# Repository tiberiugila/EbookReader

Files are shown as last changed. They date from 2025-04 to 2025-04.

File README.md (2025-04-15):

# OpenBook E-Reader

## Overview
OpenBook is a cutting-edge electronic reading device built around the ESP32-C6 microcontroller. This sophisticated gadget integrates multiple sensors and interfaces to deliver an energy-efficient reading experience with extended functionality.

## Project Gallery
The project includes various design views that showcase:
- Device exploded assembly view
- PCB layout visualization
- Component arrangement
- 3D model renderings
- Enclosure design details

## Components List (BOM)

| Componenta | Link achizitie | Link datasheet |
|---|---|---|
| 112A-TAAR-R03 ATTEND | https://store.comet.srl.ro/Catalogue/Product/43497/ | https://www.snapeda.com/parts/112A-TAAR-R03/Attend/datasheet/ |
| BD5229G-TR | https://www.digikey.com/en/products/detail/rohm-semiconductor/BD5229G-TR/3663792 | https://fscdn.rohm.com/en/products/databook/datasheet/ic/power/voltage_detector/bd52xxg-e.pdf |
| ESP32 WROVER BME680 Sensor | https://store.comet.srl.ro/Catalogue/Product/50164/ | https://www.bosch-sensortec.com/media/boschsensortec/downloads/datasheets/bst-bme680-ds001.pdf |
| LED CHG_LED | https://ro.mouser.com/ProductDetail/Kingbright/KP-1608SURCK?qs=2JU0tDl2GZ3FuyEWfBV1%2Fg== | https://www.snapeda.com/parts/KP-1608SURCK/Kingbright/datasheet/ |
| Condensator C0402 | https://ro.mouser.com/c/passive-components/capacitors/ceramic-capacitors/?q=CC0402 | https://componentsearchengine.com/Datasheets/2/CC0402MRX5R5BB106.pdf |
| Condensator Tant | https://ro.mouser.com/ProductDetail/KYOCERA-AVX/TAJW107M010RNJ?qs=Wtp%252Bf%2FAeVqIH8v1VxV%252B1Rg%3D%3D | https://ro.mouser.com/datasheet/2/40/TAJ-3165264.pdf |
| Q1 DMG2305UX-7 | https://www.digikey.com/en/products/detail/diodes-incorporated/DMG2305UX-7/4340666 | https://www.diodes.com/assets/Datasheets/DMG2305UX.pdf |
| RTC MODULE DS3231SN# | https://www.snapeda.com/parts/DS3231SN%23/Analog+Devices/view-part/?ref=eda | https://www.snapeda.com/parts/DS3231SN%23/Analog%20Devices/datasheet/ |
| ESP32 C6 WROOM-1-N8 | https://ro.mouser.com/ProductDetail/Espressif-Systems/ESP32-C6-WROOM-1-N8?qs=8Wlm6%252BaMh8ST02Gmwp74cw%3D%3D | https://www.snapeda.com/parts/ESP32-C6-WROOM-1-N8/Espressif%20Systems/datasheet/ |
| FH34SRJ-24S-0.5SH(99) | https://ro.mouser.com/ProductDetail/Hirose-Connector/FH34SRJ-24S-0.5SH99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 | https://www.snapeda.com/parts/FH34SRJ-24S-0.5SH(99)/Hirose%20Connector/datasheet/ |
| MAX 17048G+T10 | https://www.snapeda.com/parts/MAX17048G+T10/Analog+Devices/view-part/?ref=eda | https://www.snapeda.com/parts/MAX17048G+T10/Analog%20Devices/datasheet/ |
| MBR0530 Schottky Diode | https://www.snapeda.com/parts/MBR0530/Onsemi/view-part/?ref=snap | https://www.snapeda.com/parts/MBR0530/ON%20Semiconductor/datasheet/ |
| MCP73831 Power Management | https://www.snapeda.com/parts/MCP73831T-2ACI/OT/Microchip/datasheet/ | https://www.snapeda.com/parts/MCP73831T-2ACI/OT/Microchip/datasheet/ |
| PFMF.050.1 | https://ro.mouser.com/ProductDetail/EPCOS-TDK/B72520T0350K062?qs=dEfas%2FXlABIszF52uu7vrg%3D%3D | https://www.tdk-electronics.tdk.com/inf/75/db/CTVS_14/Surge_protection_series.pdf |
| PGB1010603MR | https://www.snapeda.com/parts/PGB1010603MR/Littelfuse/view-part/?ref=eda | https://www.snapeda.com/parts/PGB1010603MR/Littelfuse%20Inc./datasheet/ |
| QWIIC_RIGHT_ANGLE CONNECTOR | https://ro.mouser.com/ProductDetail/SparkFun/PRT-14417?qs=wd5RIQLrsJhgdz%2FpmZ%2F3GQ== | https://ro.mouser.com/datasheet/2/813/Qwiic_Connector_Datasheet-1223982.pdf |
| Rezistenta R0402 | https://grabcad.com/library/resistor-0402-1) | https://www.yageo.com/upload/media/product/products/datasheet/rchip/PYu-RC_Group_51_RoHS_L_12.pdf |
| SD0805S020S1R0 | https://ro.mouser.com/ProductDetail/KYOCERA-AVX/SD0805S020S1R0?qs=jCA%252BPfw4LHbpkAoSnwrdjw%3D%3D | https://ro.mouser.com/datasheet/2/40/schottky-3165252.pdf |
| Si1308EDL-T1-GE3 MOSFET | https://www.snapeda.com/parts/SI1308EDL-T1-GE3/Vishay+Siliconix/view-part/?welcome=home&ref=eda | https://www.snapeda.com/parts/SI1308EDL-T1-GE3/Vishay%20Siliconix/datasheet/ |
| USB4110-GF-A | https://ro.mouser.com/ProductDetail/GCT/USB4110-GF-A?qs=KUoIvG%2F9IlYiZvIXQjyJeA%3D%3D | https://ro.mouser.com/datasheet/2/837/GCT_USB4110_Product_Drawing___20k_cycles-3455479.pdf |
| USBLC6-2SC6Y | https://ro.mouser.com/ProductDetail/STMicroelectronics/USBLC6-2SC6Y?qs=gNDSiZmRJS%2FOgDexvXkdow%3D%3D | https://ro.mouser.com/datasheet/2/389/usblc6_2sc6y-1852505.pdf |
| W25Q512JVEIQ | https://www.snapeda.com/parts/W25Q512JVEIQ/Winbond+Electronics/view-part/?ref=eda | https://www.winbond.com/resource-files/W25Q512JV%20SPI%20RevB%2006252019%20KMS.pdf |
| XC6220A331MR-G | https://componentsearchengine.com/part-view/XC6220A331MR-G/Torex | https://product.torexsemi.com/system/files/series/xc6220.pdf |
| 744043680 BOBINA | https://ro.mouser.com/ProductDetail/Wurth-Elektronik/744043680?qs=PGXP4M47uW6VkZq%252BkzjrHA%3D%3D | https://www.we-online.com/components/products/datasheet/744043680.pdf |

## Hardware Capabilities

### Processing & Connectivity
The ESP32-C6 serves as the heart of OpenBook, providing Wi-Fi 6 and Bluetooth 5.0 LE connectivity. Its extensive GPIO capabilities enable seamless integration with various peripheral components.

### Display Technology
The e-paper display connects through an SPI interface and utilizes the BD5229G-TR driver for voltage management. MOSFET-controlled power distribution enables complete shutdown when not in use, significantly enhancing energy efficiency.

### Environmental Monitoring
The BME688 sensor delivers comprehensive environmental data including temperature, humidity, barometric pressure, and air quality (VOC) readings via I2C interface.

### Power Systems
The device features:
- MCP73831-based charging circuit supporting up to 500mA charging current
- MAX17048G+T10 battery monitoring system providing detailed charge level information
- Energy-efficient design for extended reading time

## ESP32-C6 Pin Allocation

| Component | Connected Pins | Protocol | Function |
|---|---|---|---|
| E-Paper Display | IO12, IO11, IO5, IO4| SPI | Display control and reset |
| BME688 Sensor | IO8, IO10 | I2C | Environmental monitoring |
| SD Card Interface | IO7 | SPI | External storage |
| RTC Module | IO8, IO10 | I2C | Real-time clock (shared I2C bus) |
| USB Interface | IO16, IO17 | UART | Programming and debugging |

## Implementation Process

1. Electronic schematic design and ESP32-C6 component integration
2. 2D layout development and component placement
3. Signal and power trace routing
4. Ground plane implementation on both PCB layers
5. Trace width and clearance rule application
6. Strategic connector positioning (Qwiic, USB-C)
7. Test pad placement for debugging
8. 3D model generation and mechanical compatibility verification

## Technical Notes

- Test points have been strategically positioned near board edges and critical components for easy access during testing and debugging
- Surface-mount diode pad sizes were adjusted from initial specifications to ensure reliable electrical connections and easier assembly
- Trace routing utilizes both top and bottom PCB layers for efficient signal and power distribution
- Ground planes have been implemented on both layers to optimize electrical performance

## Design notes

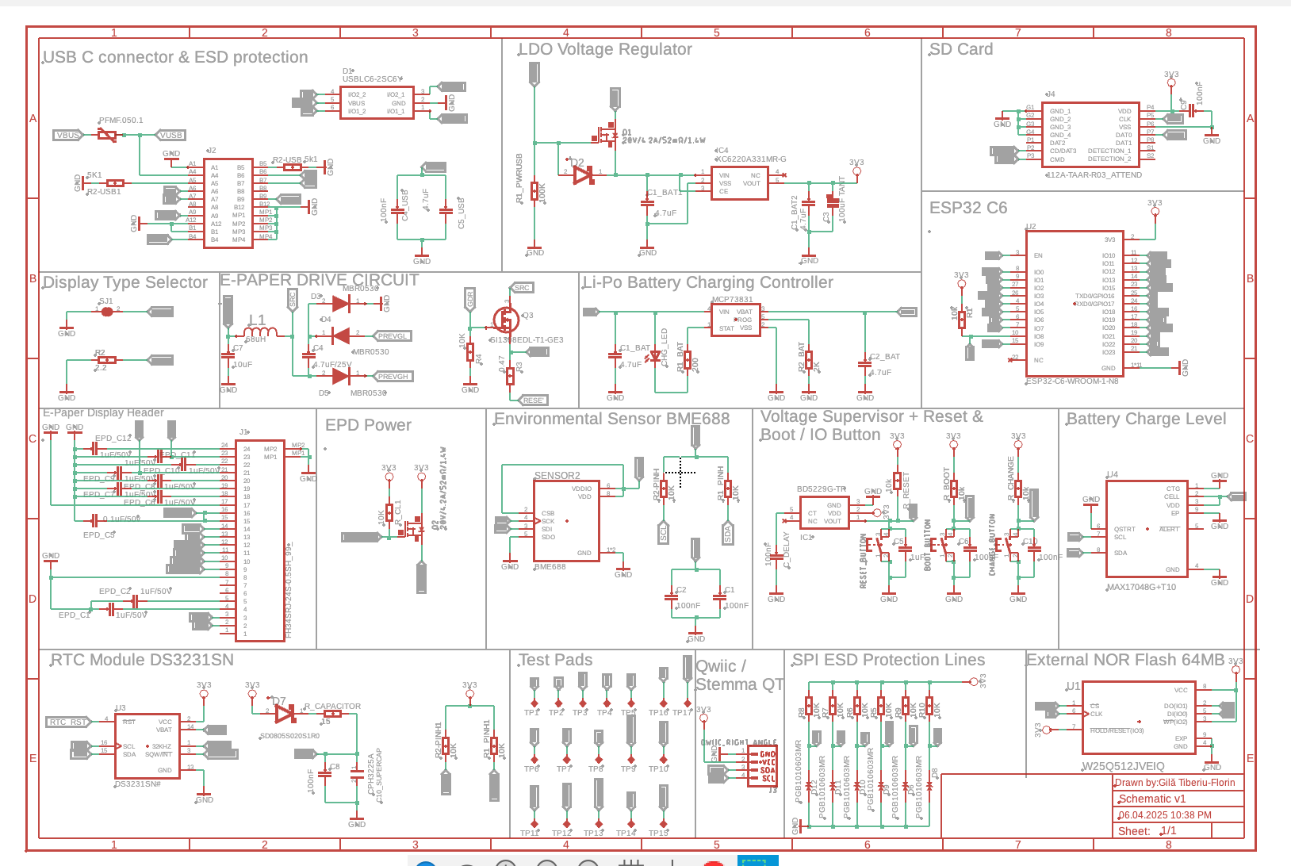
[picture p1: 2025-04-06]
Images/Schematic.png

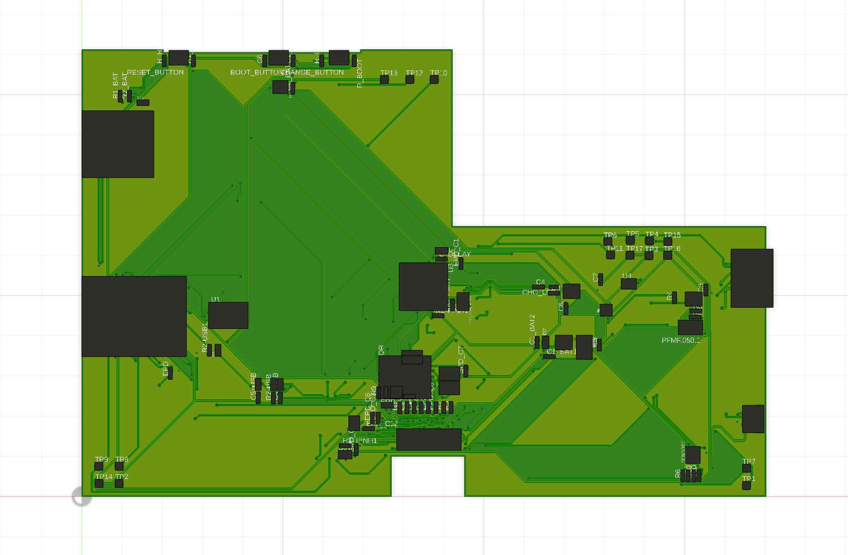
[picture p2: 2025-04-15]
Images/3D Model.png

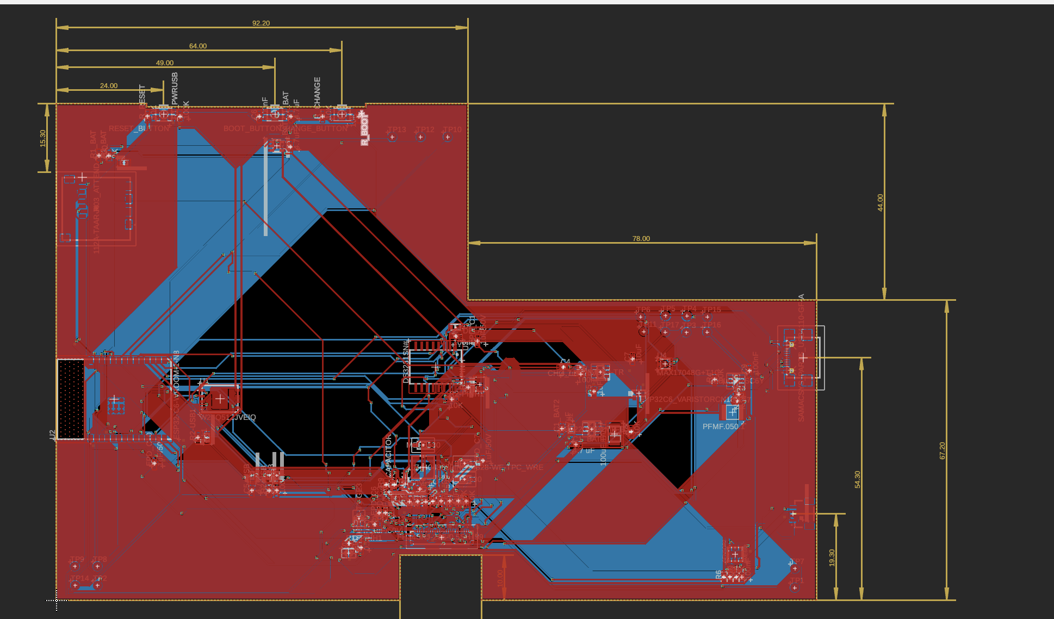
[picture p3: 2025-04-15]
Images/PCB.png

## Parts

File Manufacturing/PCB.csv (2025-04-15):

Qty | Value | Device | Package | Parts | Description | ARROW_PART_NUMBER | ARROW_PRICE-STOCK | AVAILABILITY | CENTROID_NOT_SPECIFIED | CHECK_PRICES | COPYRIGHT | DATASHEET | DESCRIPTION | DIGIKEY_DESCRIPTION | DIGIKEY_PART_NUMBER | DMG2305UX-7 | HEIGHT | LEAD_FREE | MANUFACTURER_NAME | MANUFACTURER_PART_NUMBER | MF | MFR_NAME | MOUSER_PART_NUMBER | MOUSER_PRICE-STOCK | MOUSER_TESTING_PART_NUMBER | MOUSER_TESTING_PRICE-STOCK | MP | MPN | PACKAGE | POPULARITY | PREFIX | PRICE | PROD_ID | PURCHASE-URL | ROHS | SNAPEDA_LINK | SPICEMODEL | SPICEPREFIX | TEMPERATURE_RANGE_HIGH | TEMPERATURE_RANGE_LOW | THERMALLOSS | TP_SIGNAL_NAME | VALUE
1 |  | ADAFRUIT_LEDCHIP-LED0603 | ADAFRUIT_CHIP-LED0603 | CHG_LED | LED
1 |  | SJ | SJ | SJ1 | SMD solder JUMPER |  |  |  |  |  |  |  |  |  |  |  |  |  |  |  |  |  |  |  |  |  |  |  |  | 3
1 | 0.1uF/50V | ESP32_WROVER_EAGLE-LTSPICE_CC0402 | ESP32_WROVER_EAGLE-LTSPICE_C0402 | EPD_C5 | CAPACITOR, European symbol |  |  |  |  |  |  |  |  |  |  |  |  |  |  |  |  |  |  |  |  |  |  |  |  |  |  |  |  |  |  |  | NONE | C
1 | 0.47 | ESP32_WROVER_EAGLE-LTSPICE_RR0402 | ESP32_WROVER_EAGLE-LTSPICE_R0402 | R3 | RESISTOR, European symbol |  |  |  |  |  |  |  |  |  |  |  |  |  |  |  |  |  |  |  |  |  |  |  |  |  |  |  |  |  |  |  | NONE | R
1 | 100K | ESP32_WROVER_EAGLE-LTSPICE_RR0402 | ESP32_WROVER_EAGLE-LTSPICE_R0402 | R1_PWRUSB | RESISTOR, European symbol |  |  |  |  |  |  |  |  |  |  |  |  |  |  |  |  |  |  |  |  |  |  |  |  |  |  |  |  |  |  |  | 100K | R
1 | 100nF | EAGLE-LTSPICE_CC0402 | EAGLE-LTSPICE_C0402 | C9 | CAPACITOR, European symbol |  |  |  |  |  |  |  |  |  |  |  |  |  |  |  |  |  |  |  |  |  |  |  |  |  |  |  |  |  |  |  | NONE | 100nF
1 | 100nF | EAGLE-LTSPICE_CC0402 | EAGLE-LTSPICE_C0402 | C4_USB | CAPACITOR, European symbol |  |  |  |  |  |  |  |  |  |  |  |  |  |  |  |  |  |  |  |  |  |  |  |  |  |  |  |  |  |  |  | NONE | C
6 | 100nF | ESP32_WROVER_EAGLE-LTSPICE_CC0402 | ESP32_WROVER_EAGLE-LTSPICE_C0402 | C1, C2, C6, C8, C10, C_DELAY | CAPACITOR, European symbol |  |  |  |  |  |  |  |  |  |  |  |  |  |  |  |  |  |  |  |  |  |  |  |  |  |  |  |  |  |  |  | NONE | C
1 | 100uF TANT | RCL_CPOL-EUCT3528 | RCL_CT3528 | C3 | POLARIZED CAPACITOR, European symbol |  |  |  |  |  |  |  |  |  |  |  |  |  |  |  |  |  |  |  |  |  |  |  |  | 0 |  |  |  |  |  |  |  | 100uF TANT
16 | 10K | ESP32_WROVER_EAGLE-LTSPICE_RR0402 | ESP32_WROVER_EAGLE-LTSPICE_R0402 | R1, R1_PINH, R1_PINH1, R2-PINH, R2-PINH1, R4, R5, R6, R7, R8, R9, R10, R_BOOT, R_CHANGE, R_CL1, R_RESET | RESISTOR, European symbol |  |  |  |  |  |  |  |  |  |  |  |  |  |  |  |  |  |  |  |  |  |  |  |  |  |  |  |  |  |  |  | NONE | R
1 | 10uF | ESP32_WROVER_EAGLE-LTSPICE_CC0402 | ESP32_WROVER_EAGLE-LTSPICE_C0402 | C7 | CAPACITOR, European symbol |  |  |  |  |  |  |  |  |  |  |  |  |  |  |  |  |  |  |  |  |  |  |  |  |  |  |  |  |  |  |  | NONE | C
1 | 112A-TAAR-R03_ATTEND | 112A-TAAR-R03_ATTEND | 112ATAARR03ATTEND | J4 | Micro SD Card Socket, Push-Push Type, Top Mount, SMT, H=1.83mm, 10u |  |  |  |  |  |  |  | Micro SD Card Socket | Push-Push Type | Top Mount | SMT | H=1.83mm | 10u |  |  |  | 1.9mm |  | ATTEND | 112A-TAAR-R03 ATTEND
1 | 15 | ESP32_WROVER_EAGLE-LTSPICE_RR0402 | ESP32_WROVER_EAGLE-LTSPICE_R0402 | R_CAPACITOR | RESISTOR, European symbol |  |  |  |  |  |  |  |  |  |  |  |  |  |  |  |  |  |  |  |  |  |  |  |  |  |  |  |  |  |  |  | NONE | R
1 | 1uF | ESP32_WROVER_EAGLE-LTSPICE_CC0402 | ESP32_WROVER_EAGLE-LTSPICE_C0402 | C5 | CAPACITOR, European symbol |  |  |  |  |  |  |  |  |  |  |  |  |  |  |  |  |  |  |  |  |  |  |  |  |  |  |  |  |  |  |  | NONE | C
6 | 1uF/50V | ESP32_WROVER_EAGLE-LTSPICE_CC0402 | ESP32_WROVER_EAGLE-LTSPICE_C0402 | EPD_C6, EPD_C7, EPD_C8, EPD_C9, EPD_C10, EPD_C11 | CAPACITOR, European symbol |  |  |  |  |  |  |  |  |  |  |  |  |  |  |  |  |  |  |  |  |  |  |  |  |  |  |  |  |  |  |  | NONE | C
3 | 1uF/50V | ESP32_WROVER_EAGLE-LTSPICE_CC0402 | ESP32_WROVER_EAGLE-LTSPICE_C0402 | EPD_C1, EPD_C2, EPD_C12 | CAPACITOR, European symbol |  |  |  |  |  |  |  |  |  |  |  |  |  |  |  |  |  |  |  |  |  |  |  |  |  |  |  |  |  |  |  | NONE | C
1 | 2.2 | ESP32_WROVER_EAGLE-LTSPICE_RR0402 | ESP32_WROVER_EAGLE-LTSPICE_R0402 | R2 | RESISTOR, European symbol |  |  |  |  |  |  |  |  |  |  |  |  |  |  |  |  |  |  |  |  |  |  |  |  |  |  |  |  |  |  |  | 2.2 | R
1 | 200 | ESP32_WROVER_EAGLE-LTSPICE_RR0402 | ESP32_WROVER_EAGLE-LTSPICE_R0402 | R1_BAT | RESISTOR, European symbol |  |  |  |  |  |  |  |  |  |  |  |  |  |  |  |  |  |  |  |  |  |  |  |  |  |  |  |  |  |  |  | NONE | R
2 | 20V/4.2A/52mO/1.4W | ESP32_WROVER_SPARKFUN-DISCRETESEMI_MOSFET_PCH-DMG2305UX-7 | ESP32_WROVER_SPARKFUN-DISCRETESEMI_SOT23-3 | Q1, Q2 | P-channel MOSFETs |  |  |  |  |  |  |  |  |  |  |  |  |  |  |  |  |  |  |  |  |  |  |  |  |  |  |  | TRAN-14388 |  |  |  |  |  |  |  |  |  | 20V/4.2A/52mO/1.4W
1 | 2K | ESP32_WROVER_EAGLE-LTSPICE_RR0402 | ESP32_WROVER_EAGLE-LTSPICE_R0402 | R2_BAT | RESISTOR, European symbol |  |  |  |  |  |  |  |  |  |  |  |  |  |  |  |  |  |  |  |  |  |  |  |  |  |  |  |  |  |  |  | NONE | R
1 | 4.7 uF | EAGLE-LTSPICE_CC0402 | EAGLE-LTSPICE_C0402 | C1_BAT1 | CAPACITOR, European symbol |  |  |  |  |  |  |  |  |  |  |  |  |  |  |  |  |  |  |  |  |  |  |  |  |  |  |  |  |  |  |  | NONE | C |  |  | 4.7 uF
1 | 4.7uF | EAGLE-LTSPICE_CC0402 | EAGLE-LTSPICE_C0402 | C1_BAT2 | CAPACITOR, European symbol |  |  |  |  |  |  |  |  |  |  |  |  |  |  |  |  |  |  |  |  |  |  |  |  |  |  |  |  |  |  |  | NONE | 4.7uF
1 | 4.7uF | EAGLE-LTSPICE_CC0402 | EAGLE-LTSPICE_C0402 | C5_USB | CAPACITOR, European symbol |  |  |  |  |  |  |  |  |  |  |  |  |  |  |  |  |  |  |  |  |  |  |  |  |  |  |  |  |  |  |  | NONE | C
2 | 4.7uF | ESP32_WROVER_EAGLE-LTSPICE_CC0402 | ESP32_WROVER_EAGLE-LTSPICE_C0402 | C1_BAT, C2_BAT | CAPACITOR, European symbol |  |  |  |  |  |  |  |  |  |  |  |  |  |  |  |  |  |  |  |  |  |  |  |  |  |  |  |  |  |  |  | NONE | C
1 | 4.7uF/25V | ESP32_WROVER_EAGLE-LTSPICE_CC0402 | ESP32_WROVER_EAGLE-LTSPICE_C0402 | C4 | CAPACITOR, European symbol |  |  |  |  |  |  |  |  |  |  |  |  |  |  |  |  |  |  |  |  |  |  |  |  |  |  |  |  |  |  |  | NONE | C
2 | 5k1 | ESP32_WROVER_EAGLE-LTSPICE_RR0402 | ESP32_WROVER_EAGLE-LTSPICE_R0402 | R2-USB, R2-USB1 | RESISTOR, European symbol |  |  |  |  |  |  |  |  |  |  |  |  |  |  |  |  |  |  |  |  |  |  |  |  |  |  |  |  |  |  |  | NONE | R
1 | 744043680IND_4828-WE-TPC_WRE | 744043680IND_4828-WE-TPC_WRE | IND_4828-WE-TPC_WRE | L1 |  |  |  |  |  |  | Copyright (C) 2024 Ultra Librarian. All rights reserved. |  |  |  |  |  |  |  |  | 68uH |  | Wurth Electronics
1 | BD5229G-TR | BD5229G-TR | SOT95P280X125-5N | IC1 | Voltage Detector with Adjustable Delay Time: CMOS processes are utilized to develop high precision, low current consumption CMOS reset ICs that allow arbitrary setting of the delay time. The extensive lineup includes both Nch Open Drain and CMOS output types in a wide range of detection voltages (from 2.3V to 6.0V, in 0.1V steps), enabling selection of the ideal solution based on customer requirements. In addition, the entire series is of course both lead-free and RoHS-compliant. |  |  |  |  |  |  |  | Voltage Detector with Adjustable Delay Time: CMOS processes are utilized to develop high precision | low current consumption CMOS reset ICs that allow arbitrary setting of the delay time. The extensive lineup includes both Nch Open Drain and CMOS output types in a wide range of detection voltages (from 2.3V to 6.0V | in 0.1V steps) | enabling selection of the ideal solution based on customer requirements. In addition | the entire series is of course both lead-free and RoHS-compliant. |  |  |  | 1.25mm |  | ROHM Semiconductor | BD5229G-TR |  |  | 755-BD5229G-TR | https://www.mouser.co.uk/ProductDetail/ROHM-Semiconductor/BD5229G-TR?qs=4kLU8WoGk0vvnhrrYwdszw%3D%3D
1 | BME688 | ESP32_WROVER_BME680_BME680 | ESP32_WROVER_BME680_PSON80P300X300X100-8N | SENSOR2 | Integrated Environmental Unit |  |  | Unavailable |  |  |  |  | Integrated Environmental Unit |  |  |  |  |  |  |  | Bosch Sensortec |  |  |  |  |  | BME680 |  | LGA-8 Bosch Tools |  |  | None
3 | BUTTON_CUSYOMV1 | BUTTON_CUSYOMV1 | MYBUTTON | BOOT_BUTTON, CHANGE_BUTTON, RESET_BUTTON
1 | CPH3225A | CPH3225A | CAPCP3225X100N | C10_SUPERCAP | Cap 0.011F 3.3V 1210 Flat Check availability |  |  | Not in stock |  | https://www.snapeda.com/parts/CPH3225A/Seiko+Instruments/view-part/?ref=eda |  |  | 11 mF (EDLC) Supercapacitor 3.3 V 1210 (3225 Metric) - - |  |  |  |  |  |  |  | Seiko Instruments |  |  |  |  |  | CPH3225A |  | 1210 Seiko |  |  | None |  | https://www.snapeda.com/api/url_track_click_mouser/?unipart_id=562593&manufacturer=Seiko Instruments&part_name=CPH3225A&search_term=None |  | https://www.snapeda.com/parts/CPH3225A/Seiko+Instruments/view-part/?ref=snap
1 | DS3231SN# | DS3231SN# | SOIC127P1032X265-16N | U3 | Real Time Clock Serial 16-Pin SOIC W T/R Check availability |  |  | In Stock |  | https://www.snapeda.com/parts/DS3231SN%23/Analog+Devices/view-part/?ref=eda |  |  | Extremely Accurate I²C-Integrated RTC/TCXO/Crystal |  |  |  |  |  |  |  | Analog Devices |  |  |  |  |  | DS3231SN# |  | SOIC-16 Maxim |  |  | None |  | https://www.snapeda.com/api/url_track_click_mouser/?unipart_id=99048&manufacturer=Analog Devices&part_name=DS3231SN#&search_term=None |  | https://www.snapeda.com/parts/DS3231SN%23/Analog+Devices/view-part/?ref=snap
1 | ESP32-C6-WROOM-1-N8 | ESP32-C6-WROOM-1-N8 | XCVR_ESP32-C6-WROOM-1-N8 | U2 | Check availability |  |  | In Stock |  | https://www.snapeda.com/parts/ESP32-C6-WROOM-1-N8/Espressif+Systems/view-part/?ref=eda |  |  | Multiprotocol Modules ESP32-C6 module | Wi-Fi 6 in 2.4 GHz band | Bluetooth 5 | Zigbee 3.0 and Thread. ESP34-WROOM Compatible - ENGINEERING SAMPLE |  |  |  |  |  |  |  | Espressif Systems |  |  |  |  |  | ESP32-C6-WROOM-1-N8 |  | None |  |  | None |  |  |  | https://www.snapeda.com/parts/ESP32-C6-WROOM-1-N8/Espressif+Systems/view-part/?ref=snap
1 | ESP32C6_VARISTORCN1812 | ESP32C6_VARISTORCN1812 | ESP32C6_VARISTOR_CT/CN1812 | PFMF.050.1 | VARISTOR |  |  |  |  |  |  |  |  |  |  |  |  |  |  |  |  |  |  |  |  |  |  |  |  | 0
1 | ESP32_WROVER_AVX---SD0805S020S1R0_AVX_SD0805S020S1R0_0_0AVX_SD0805S020S1R0_0_0 | ESP32_WROVER_AVX---SD0805S020S1R0_AVX_SD0805S020S1R0_0_0AVX_SD0805S020S1R0_0_0 | ESP32_WROVER_AVX---SD0805S020S1R0_AVX_SD0805S020S1R0_0 | D2 | Schottky Barrier Rectifier Diode |  |  |  | No |  |  | http://datasheets.avx.com/schottky.pdf |  | DIODE SCHOTTKY 20V 1A 0805 | 478-7800-1-ND |  |  | yes |  |  | AVX |  | 581-SD0805S020S1R0 |  |  |  |  |  | 0805 (2012 metric) |  | D |  |  |  | yes |  |  |  | +125°C | -55°C
1 | ESP32_WROVER_SPARKFUN-IC-POWER_MCP73831 | ESP32_WROVER_SPARKFUN-IC-POWER_MCP73831 | ESP32_WROVER_SPARKFUN-IC-POWER_SOT23-5 | MCP73831 | MCP73831T Li-Ion, Li-Pol Controller |  |  |  |  |  |  |  |  |  |  |  |  |  |  |  |  |  |  |  |  |  |  |  |  |  |  |  | IC-09995
1 | FH34SRJ-24S-0.5SH_99_ | FH34SRJ-24S-0.5SH_99_ | FH34SRJ24S05SH99 | J1 | (0.50mm) Surface Mount, Right Angle |  |  |  |  |  |  |  | 24 Position FFC | FPC Connector Contacts | (0.50mm) Surface Mount | Right Angle |  |  |  | 1.1mm |  | Hirose | FH34SRJ-24S-0.5SH(99) |  |  | 798-FH34SRJ24S05SH99 | https://www.mouser.co.uk/ProductDetail/Hirose-Connector/FH34SRJ-24S-0.5SH99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
1 | MAX17048G+T10 | MAX17048G+T10 | SON50P200X200X80-9N | U4 | Check availability |  |  | In Stock |  | https://www.snapeda.com/parts/MAX17048G+T10/Analog+Devices/view-part/?ref=eda |  |  | 3µA 1-Cell/2-Cell Fuel Gauge with ModelGauge |  |  |  |  |  |  |  | Analog Devices |  |  |  |  |  | MAX17048G+T10 |  | TDFN-8 Maxim |  |  | None |  | https://www.snapeda.com/api/url_track_click_mouser/?unipart_id=329239&manufacturer=Analog Devices&part_name=MAX17048G+T10&search_term=None |  | https://www.snapeda.com/parts/MAX17048G+T10/Analog+Devices/view-part/?ref=snap
3 | MBR0530 | MBR0530 | SOD3716X135N | D3, D4, D5 | ON SEMICONDUCTOR - MBR0530 - DIODE, SCHOTTKY, 0.5A, 30V, SOD-123 |  |  | In Stock |  | https://www.snapeda.com/parts/MBR0530/Onsemi/view-part/?ref=eda |  |  | Diode Schottky 30 V 500mA Surface Mount SOD-123 |  |  |  |  |  |  |  | ON Semiconductor |  |  |  |  |  | MBR0530 |  | SOD-123-2 ON Semiconductor |  |  | None |  | https://www.snapeda.com/api/url_track_click_mouser/?unipart_id=179458&manufacturer=ON Semiconductor&part_name=MBR0530&search_term=None |  | https://www.snapeda.com/parts/MBR0530/Onsemi/view-part/?ref=snap
6 | PGB1010603MR | PGB1010603MR | DIOC1608X36N | D6, D8, D9, D10, D11, D12 | Check availability |  |  | In Stock |  | https://www.snapeda.com/parts/PGB1010603MR/Littelfuse/view-part/?ref=eda |  |  | 150V (Typ) Clamp - Ipp Tvs Diode Surface Mount 0603 (1608 Metric) |  |  |  |  |  |  |  | Littelfuse Inc. |  |  |  |  |  | PGB1010603MR |  | 0603 Littelfuse Inc. |  |  | None |  | https://www.snapeda.com/api/url_track_click_mouser/?unipart_id=5659453&manufacturer=Littelfuse Inc.&part_name=PGB1010603MR&search_term=None |  | https://www.snapeda.com/parts/PGB1010603MR/Littelfuse/view-part/?ref=snap
1 | QWIIC_RIGHT_ANGLE | QWIIC_CONNECTORJS-1MM | JST04_1MM_RA | J3 | SparkFun I2C Standard Qwiic Connector |  |  |  |  |  |  |  |  |  |  |  |  |  |  |  |  |  |  |  |  |  |  |  |  |  |  |  | CONN-13694 |  |  |  |  |  |  |  |  |  | QWIIC_RIGHT_ANGLE
1 | SAMACSYS_PARTS_USB4110-GF-A | SAMACSYS_PARTS_USB4110-GF-A | SAMACSYS_PARTS_USB4110GFA | J2 | CONN USB 2.0 TYPE-C R/A SMT |  |  |  |  |  |  |  | CONN USB 2.0 TYPE-C R/A SMT |  |  |  | 3.26mm |  | GCT (GLOBAL CONNECTOR TECHNOLOGY) | USB4110-GF-A |  |  | 640-USB4110-GF-A | https://www.mouser.co.uk/ProductDetail/GCT/USB4110-GF-A?qs=KUoIvG%2F9IlYiZvIXQjyJeA%3D%3D
1 | SD0805S020S1R0 | ESP32_WROVER_AVX---SD0805S020S1R0_AVX_SD0805S020S1R0_0_0AVX_SD0805S020S1R0_0_0 | ESP32_WROVER_AVX---SD0805S020S1R0_AVX_SD0805S020S1R0_0 | D7 | Schottky Barrier Rectifier Diode |  |  |  | No |  |  | http://datasheets.avx.com/schottky.pdf |  | DIODE SCHOTTKY 20V 1A 0805 | 478-7800-1-ND |  |  | yes |  |  | AVX |  | 581-SD0805S020S1R0 |  |  |  |  |  | 0805 (2012 metric) |  | D |  |  |  | yes |  |  |  | +125°C | -55°C
1 | SI1308EDL-T1-GE3 | SI1308EDL-T1-GE3 | SOT65P210X110-3N | Q3 | MOSFET N-Ch 30V 1.5A TrenchFET SC70 Vishay Si1308EDL-T1-GE3 N-channel MOSFET Transistor, 1.5 A, 30 V, 3-Pin SC-70 |  |  | In Stock |  | https://www.snapeda.com/parts/SI1308EDL-T1-GE3/Vishay+Siliconix/view-part/?ref=eda |  |  | Si1308EDL-T1-GE3 N-channel MOSFET Transistor | 1.5 A | 30 V | 3-Pin SC-70 | Siliconix / Vishay SI1308EDL-T1-GE3 |  |  |  |  |  |  |  | Vishay Siliconix |  |  |  |  |  | SI1308EDL-T1-GE3 |  | SOT-323 Vishay Semiconductor |  |  | None |  | https://www.snapeda.com/api/url_track_click_mouser/?unipart_id=274603&manufacturer=Vishay Siliconix&part_name=SI1308EDL-T1-GE3&search_term=None |  | https://www.snapeda.com/parts/SI1308EDL-T1-GE3/Vishay+Siliconix/view-part/?ref=snap
17 | TPTP20R | TPTP20R | TP20R | TP1, TP2, TP3, TP4, TP5, TP6, TP7, TP8, TP9, TP10, TP11, TP12, TP13, TP14, TP15, TP16, TP17 | Test pad |  |  |  |  |  |  |  |  |  |  |  |  |  |  |  |  |  |  |  |  |  |  |  |  | 2
1 | USBLC6-2SC6Y | USBLC6-2SC6Y | SOT95P280X145-6N | D1 | Low Cap. ESD Protection Auto SOT-23-6 STMicroelectronics USBLC6-2SC6Y, Dual Uni-Directional TVS Diode Array, 6-Pin SOT-23 |  |  | In Stock |  | https://www.snapeda.com/parts/USBLC6-2SC6Y/STMicroelectronics/view-part/?ref=eda |  |  | 17V Clamp 5A (8/20µs) Ipp Tvs Diode Surface Mount SOT-23-6 |  |  |  |  |  |  |  | STMicroelectronics |  |  |  |  |  | USBLC6-2SC6Y |  | SOT-23-6 STMicroelectronics |  |  | None |  |  |  | https://www.snapeda.com/parts/USBLC6-2SC6Y/STMicroelectronics/view-part/?ref=snap
1 | W25Q512JVEIQ | W25Q512JVEIQ | SON127P600X800X80-9N | U1 | Check availability |  |  | In Stock |  | https://www.snapeda.com/parts/W25Q512JVEIQ/Winbond+Electronics/view-part/?ref=eda |  |  | FLASH - NOR Memory IC 512Mb (64M x 8) SPI - Quad I/O 133 MHz 8-WSON (8x6) |  |  |  |  |  |  |  | Winbond Electronics |  |  |  |  |  | W25Q512JVEIQ |  | Package |  |  | None |  |  |  | https://www.snapeda.com/parts/W25Q512JVEIQ/Winbond+Electronics/view-part/?ref=snap
1 | XC6220A331MR-G | XC6220A331MR-G | SOT95P280X120-5N | IC4 | LDO Voltage Regulators |  |  |  |  |  |  |  | LDO Voltage Regulators |  |  |  | 1.2mm |  | Torex | XC6220A331MR-G |  |  | 865-XC6220A331MR-G | https://www.mouser.co.uk/ProductDetail/Torex-Semiconductor/XC6220A331MR-G?qs=AsjdqWjXhJ8ZSWznL1J0gg%3D%3D

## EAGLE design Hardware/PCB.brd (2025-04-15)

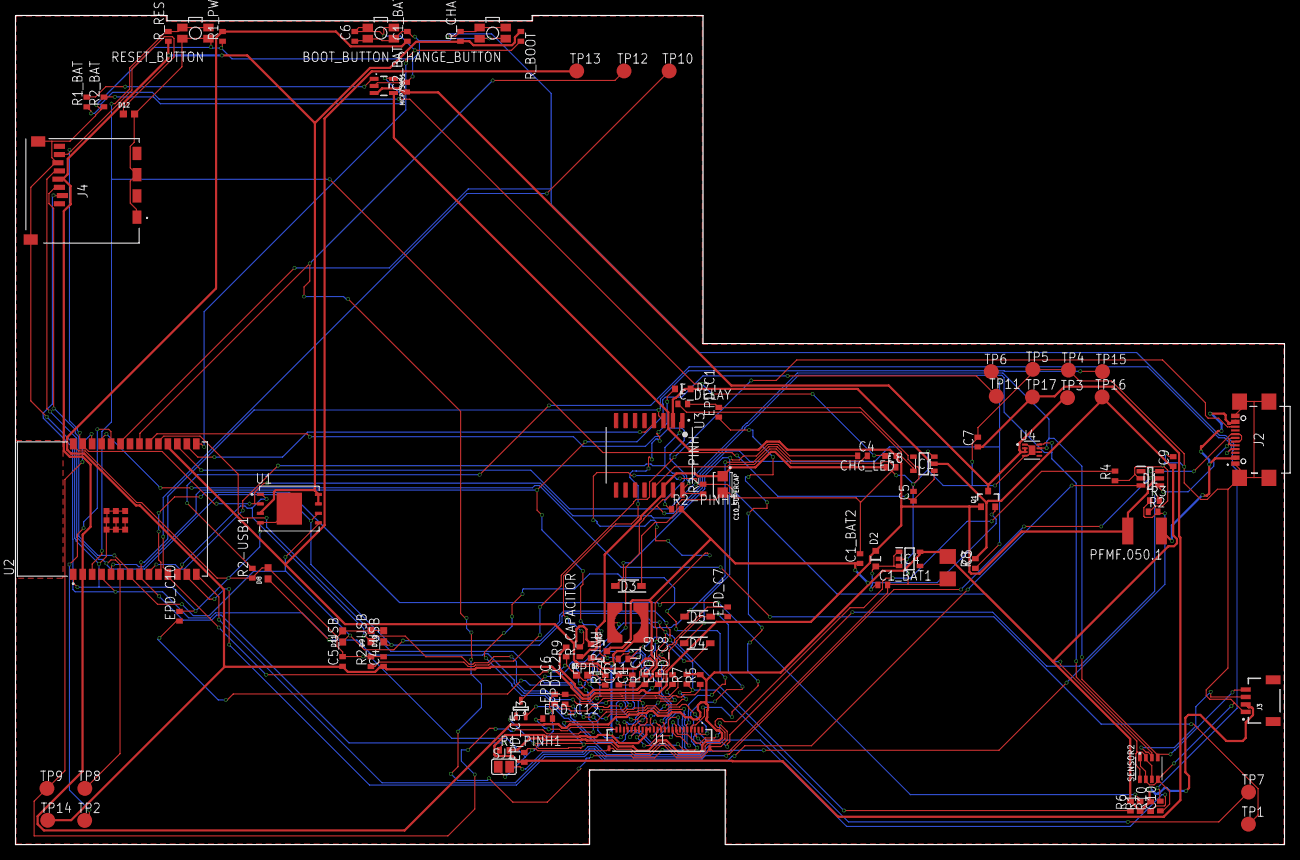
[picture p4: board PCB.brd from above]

Board: 2 copper layers, 170.2 x 111.2 mm, 103 parts (0 on the bottom side), 55 nets.

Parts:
BOOT_BUTTON: BUTTON_CUSYOMV1; MYBUTTON
C1, C2, C6, C8, C10: 100nF; ESP32_WROVER_EAGLE-LTSPICE_C0402
C1_BAT, C2_BAT: 4.7uF; ESP32_WROVER_EAGLE-LTSPICE_C0402
C1_BAT1: 4.7 uF; EAGLE-LTSPICE_C0402
C1_BAT2, C5_USB: 4.7uF; EAGLE-LTSPICE_C0402
C3: 100uF TANT; RCL_CT3528
C4: 4.7uF/25V; ESP32_WROVER_EAGLE-LTSPICE_C0402
C4_USB, C9: 100nF; EAGLE-LTSPICE_C0402
C5: 1uF; ESP32_WROVER_EAGLE-LTSPICE_C0402
C7: 10uF; ESP32_WROVER_EAGLE-LTSPICE_C0402
C10_SUPERCAP: CPH3225A; CAPCP3225X100N
CHANGE_BUTTON: BUTTON_CUSYOMV1; MYBUTTON
CHG_LED: ADAFRUIT_CHIP-LED0603
C_DELAY: 100nF; ESP32_WROVER_EAGLE-LTSPICE_C0402
D1: USBLC6-2SC6Y; SOT95P280X145-6N
D2: ESP32_WROVER_AVX---SD0805S020S1R0_AVX_SD0805S020S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; ESP32_WROVER_AVX---SD0805S020S1R0_AVX_SD0805S020S1R0_0
D3, D4, D5: MBR0530; SOD3716X135N
D6, D8, D9, D10, D11, D12: PGB1010603MR; DIOC1608X36N
D7: SD0805S020S1R0; ESP32_WROVER_AVX---SD0805S020S1R0_AVX_SD0805S020S1R0_0
EPD_C1, EPD_C2, EPD_C6, EPD_C7, EPD_C8, EPD_C9, EPD_C10, EPD_C11, EPD_C12: 1uF/50V; ESP32_WROVER_EAGLE-LTSPICE_C0402
EPD_C5: 0.1uF/50V; ESP32_WROVER_EAGLE-LTSPICE_C0402
IC1: BD5229G-TR; SOT95P280X125-5N
IC4: XC6220A331MR-G; SOT95P280X120-5N
J1: FH34SRJ-24S-0.5SH_99_; FH34SRJ24S05SH99
J2: SAMACSYS_PARTS_USB4110-GF-A; SAMACSYS_PARTS_USB4110GFA
J3: QWIIC_RIGHT_ANGLE; JST04_1MM_RA
J4: 112A-TAAR-R03_ATTEND; 112ATAARR03ATTEND
L1: 744043680IND_4828-WE-TPC_WRE; IND_4828-WE-TPC_WRE
MCP73831: ESP32_WROVER_SPARKFUN-IC-POWER_MCP73831; ESP32_WROVER_SPARKFUN-IC-POWER_SOT23-5
PFMF.050.1: ESP32C6_VARISTORCN1812; ESP32C6_VARISTOR_CT/CN1812
Q1, Q2: 20V/4.2A/52mΩ/1.4W; ESP32_WROVER_SPARKFUN-DISCRETESEMI_SOT23-3
Q3: SI1308EDL-T1-GE3; SOT65P210X110-3N
R1, R1_PINH, R1_PINH1, R2-PINH, R2-PINH1, R4, R5, R6, R7, R8, R9, R10: 10K; ESP32_WROVER_EAGLE-LTSPICE_R0402
R1_BAT: 200; ESP32_WROVER_EAGLE-LTSPICE_R0402
R1_PWRUSB: 100K; ESP32_WROVER_EAGLE-LTSPICE_R0402
R2: 2.2; ESP32_WROVER_EAGLE-LTSPICE_R0402
R2-USB, R2-USB1: 5k1; ESP32_WROVER_EAGLE-LTSPICE_R0402
R2_BAT: 2K; ESP32_WROVER_EAGLE-LTSPICE_R0402
R3: 0.47; ESP32_WROVER_EAGLE-LTSPICE_R0402
RESET_BUTTON: BUTTON_CUSYOMV1; MYBUTTON
R_BOOT: 10K; ESP32_WROVER_EAGLE-LTSPICE_R0402
R_CAPACITOR: 15; ESP32_WROVER_EAGLE-LTSPICE_R0402
R_CHANGE: 10K; ESP32_WROVER_EAGLE-LTSPICE_R0402
R_CL1: 10K; ESP32_WROVER_EAGLE-LTSPICE_R0402
R_RESET: 10K; ESP32_WROVER_EAGLE-LTSPICE_R0402
SENSOR2: BME688; ESP32_WROVER_BME680_PSON80P300X300X100-8N
SJ1: SJ
TP1, TP2, TP3, TP4, TP5, TP6, TP7, TP8, TP9, TP10, TP11, TP12, TP13, TP14, TP15, TP16, TP17: TPTP20R; TP20R
U1: W25Q512JVEIQ; SON127P600X800X80-9N
U2: ESP32-C6-WROOM-1-N8; XCVR_ESP32-C6-WROOM-1-N8
U3: DS3231SN#; SOIC127P1032X265-16N
U4: MAX17048G+T10; SON50P200X200X80-9N

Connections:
3V3: C1_BAT2.1, C3.+, C9.1, D7.2, IC1.2, IC4.5, J3.2, J4.P4, Q2.3, R1.1, R1_PINH1.2, R2-PINH1.2, R5.2, R6.2, R7.2, R8.2, R9.2, R10.2, R_BOOT.1, R_CHANGE.1, R_CL1.1, R_RESET.1, TP16.TP, U1.3, U1.7, U1.8, U2.2, U3.2
32KHZ: R2-PINH1.1, U2.9, U3.1
DN: D1.4, J2.A7, J2.B7
DP: D1.6, J2.A6, J2.B6
EPD_3V3: C7.1, EPD_C5.1, J1.15, J1.16, L1.2, Q2.2, TP17.TP
EPD_3V3_C: Q2.1, R_CL1.2, TP13.TP, U2.18
EPD_BUSY: J1.9, TP9.TP, U2.26
EPD_CS: D6.1, J1.12, R9.1, TP10.TP, U2.11
EPD_DC: J1.11, TP11.TP, U2.5
EPD_RST: J1.10, TP12.TP, U2.21
FLASH_CS: D9.1, R5.1, U1.1, U2.12
GDR: J1.2, Q3.1, R4.2
GND: BOOT_BUTTON.1, BOOT_BUTTON.2, C1.2, C1_BAT.2, C1_BAT1.2, C1_BAT2.2, C2.2, C2_BAT.2, C3.-, C4_USB.2, C5.2, C5_USB.2, C6.1, C7.2, C8.2, C9.2, C10.1, C10_SUPERCAP.2, CHANGE_BUTTON.1, CHANGE_BUTTON.2, C_DELAY.2, D1.2, D3.1, D6.2, D8.2, D9.2, D10.2, D11.2, D12.2, EPD_C1.2, EPD_C2.2, EPD_C5.2, EPD_C6.2, EPD_C7.2, EPD_C8.2, EPD_C9.2, EPD_C10.2, EPD_C11.2, EPD_C12.2, IC1.3, IC4.2, J1.8, J1.17, J1.MP1, J1.MP2, J2.A1, J2.A12, J2.B1, J2.B12, J2.MP1, J2.MP2, J2.MP3, J2.MP4, J3.1, J4.G1, J4.G2, J4.G3, J4.G4, J4.P6, MCP73831.2, R1_PWRUSB.1, R2.1, R2-USB.2, R2-USB1.1, R2_BAT.1, R4.1, RESET_BUTTON.1, RESET_BUTTON.2, SENSOR2.1, SENSOR2.5, SENSOR2.7, SJ1.1, TP4.TP, TP5.TP, U1.4, U1.9, U2.1, U2.28, U2.29_1, U2.29_2, U2.29_3, U2.29_4, U2.29_5, U2.29_6, U2.29_7, U2.29_8, U2.29_9, U3.13, U4.1, U4.4, U4.6, U4.9
GPIO8: R1.2, U2.10
I2C_PW: C1.1, C2.1, R1_PINH.2, R2-PINH.2, SENSOR2.2, SENSOR2.6, SENSOR2.8, U2.17
INT_RTC: R1_PINH1.1, TP15.TP, U2.8, U3.3
IO/BOOT: BOOT_BUTTON.3, BOOT_BUTTON.4, C6.2, R_BOOT.2, U2.15
IO/CHANGE: C10.2, CHANGE_BUTTON.3, CHANGE_BUTTON.4, R_CHANGE.2, U2.23
MISO: D12.1, J4.P7, R8.1, TP6.TP, U1.2, U2.27
MOSI: D11.1, J1.14, J4.P3, R7.1, TP7.TP, U1.5, U2.7
unnamed: J2.A5, R2-USB1.2
unnamed: J2.B5, R2-USB.1
unnamed: C4.1, D3.2, D4.1
unnamed: C1_BAT1.1, D2.1, IC4.1, IC4.3, Q1.2
unnamed: C_DELAY.1, IC1.5
unnamed: CHG_LED.C, R1_BAT.1
unnamed: MCP73831.1, R1_BAT.2
unnamed: MCP73831.5, R2_BAT.2
unnamed: EPD_C12.1, J1.24
unnamed: EPD_C6.1, J1.18
unnamed: EPD_C7.1, J1.19
unnamed: EPD_C8.1, J1.20
unnamed: EPD_C10.1, J1.22
unnamed: D7.1, R_CAPACITOR.2
unnamed: EPD_C2.1, J1.5
unnamed: EPD_C1.1, J1.4
PREVGH: D5.1, EPD_C9.1, J1.21
PREVGL: D4.2, EPD_C11.1, J1.23
RESE: J1.3, Q3.2, R3.2
RESE': R2.2, R3.1, SJ1.2
RESET: C5.1, IC1.1, RESET_BUTTON.3, RESET_BUTTON.4, R_RESET.2, U2.3
RTC_RST: U2.16, U3.4
RX: TP2.TP, U2.24
SCK: D10.1, J1.13, J4.P5, R6.1, TP8.TP, U1.6, U2.6
SCL: J3.4, R2-PINH.1, SENSOR2.4, U2.20, U3.16, U4.7
SDA: J3.3, R1_PINH.1, SENSOR2.3, U2.19, U3.15, U4.8
SRC: C4.2, D5.2, L1.1, Q3.3
SS_SD: D8.1, J4.P2, R10.1, U2.4
TX: TP1.TP, U2.25
USB_D+: D1.1, U2.14
USB_D-: D1.3, U2.13
VBAT: C2_BAT.1, MCP73831.3, Q1.3, TP3.TP, U4.2, U4.3
VBUS: C1_BAT.1, C4_USB.1, C5_USB.1, CHG_LED.A, D1.5, D2.2, MCP73831.4, PFMF.050.1.2, Q1.1, R1_PWRUSB.2, TP14.TP
VRTC: C8.1, C10_SUPERCAP.1, R_CAPACITOR.1, U3.14
VUSB: J2.A4, J2.A9, J2.B4, J2.B9, PFMF.050.1.1

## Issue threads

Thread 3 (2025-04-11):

Structura cerută nerespectată

biancamih, 2025-04-11:
Proiectul nu respectă structura ierarhică cerută, deoarece nu sunt prezente următoarele directoare și fișiere: în cadrul Hardware lipsește fișierul cu board-ul (.brd); în cadrul Manufacturing lipsește fișierul gerbers.zip, fișierul Bill of Materials (.bom) și fișierul Pick and Place (.cpl); în cadrul Mechanical lipsește fișierul 3D cu dispozitivul complet (PCB + baterie + display + carcasa) - exploded view (.step) și fișierul 3D Fusion360 cu dispozitivul complet; de asemenea, lipsește fișierul LICENSE și README.md nu are conținut.

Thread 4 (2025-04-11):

Lipsă detalii complete

biancamih, 2025-04-11:
În schematic, tranzistorii folosiți în secțiuneile EPD Power și LDO Voltage Regulator sunt marcați doar cu simbolul lor, fără a include detaliile complete ale componentei, cum ar fi numele (DMG2305UX-7). Pentru D2 lipsește numele SD0805S020S1R0.
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

Closed 2025-04-15.

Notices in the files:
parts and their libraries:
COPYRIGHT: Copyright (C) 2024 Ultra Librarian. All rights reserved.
